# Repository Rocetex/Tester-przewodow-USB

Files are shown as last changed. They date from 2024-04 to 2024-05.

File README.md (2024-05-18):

# Tester przewodow USB
## Wstęp:
Jako projekt wstępnie wybrano tester przewodów USB. Wymagania przyjęte do tego projektu były następujące: stosunkowo niski koszt, prostota obsługi, kompaktowość i wszechstronność. Zdecydowano się, aby tester przeznaczony był dla przewodów USB type C - USB type C. Po podłączeniu przewodów do urządzenia  powinno ono podświetleniem poszczególnych diod ukazywać w jakim trybie może działać dany przewód, oraz możliwe uszkodzenia i cięcia budżetowe producenta w jego strukturze. 

## Założenia projektu:
* Możliwość testu 2 typów przewodów: USB A -> USB C oraz USB C -> USB C
* Dwa tryby częstotliwości pracy układu
* Kompaktowość urządzenia
* Niska cena
  
## Schemat i projekt układu
Wstępny zamysł projektu był następujący. Odpowiednio zaprojektowany system zegara CLK oparty o układ scalony NE555. Następnie sygnał ten przechodzi na 5 przerzutników typu JK działających w układzie licznika synchronicznego od 0 - 24, dzięki czemu możliwe było obsłużenie wszystkich 25 sygnałów pełnego złącza USB type C (a dokładniej 24 pinów sygnałowych oraz shielda). W ten sposób zaprojektowano układ licznika 5 bitowego. Sygnał z poszczególnych wyjść liczników trafia na dwa 4 bitowe dekodery połączone w odpowiedni sposób, zamiast na jeden dekoder 5 bitowy. Wynika to z faktu dostępności i ceny. Układ dwóch 4 bitowych dekoderów jest tańszy i łatwiej dostępny. Sygnał z poszczególnych wyjść dekoderów trafiał na odpowiednie mosfety typu P, a one po otrzymaniu sygnału załączeniowego (logiczne “0”) zaczynały przewodzić do odpowiedniego pinu złącza USB C. Następnie przez przewód sygnał trafiał na odpowiednie szeregowo połączone rezystory i diody, które zaczynały świecić, sygnalizująć działanie danego pinu.



## Instrukcja obsługi:
Płytkę należy zasilić napięciem 5V. 
Switch S1 odowiada za resetowanie układu.
Przełącznik S3 odpowiada za wybranie częstotliwości pracy układu
Przełącznik S4 odpowiada za wybranie trybu pracy:
1) USB typu A
2) USB typu C
Aby przetestować przewód USB A -> USB C:
- Podłączyć zasilanie do płytki
- Ustawić oczelowamą częstotliwość pracy układu
- Ustawić tryb pracy na USB A
- Wpiąć przewód z złącze USB A (oznaczone na płytce jako J3) oraz w wyjściowe złącze USB typu C (J2)
Aby przetestować przewód USB C -> USB C:
- Podłączyć zasilanie do płytki
- Ustawić oczelowamą częstotliwość pracy układu
- Ustawić tryb pracy na USB C
- Wpiąć przewód z złącze USB C (oznaczone na płytce jako J1) oraz w wyjściowe złącze USB typu C (J2)

## Błędy w konstrukcji płytki:
- Kondensator C3 należy przylutować równolegle do masy oraz do zwartych padów miejsca kondensatora
- Pomimo wykonania symulacji zauważono problem z zamykaniem się mosfetów, z tego powodu zaleca się użycie tranzystorów PNP oraz rezystorów na bramce 1k Ohm

## Prezentacja układu:






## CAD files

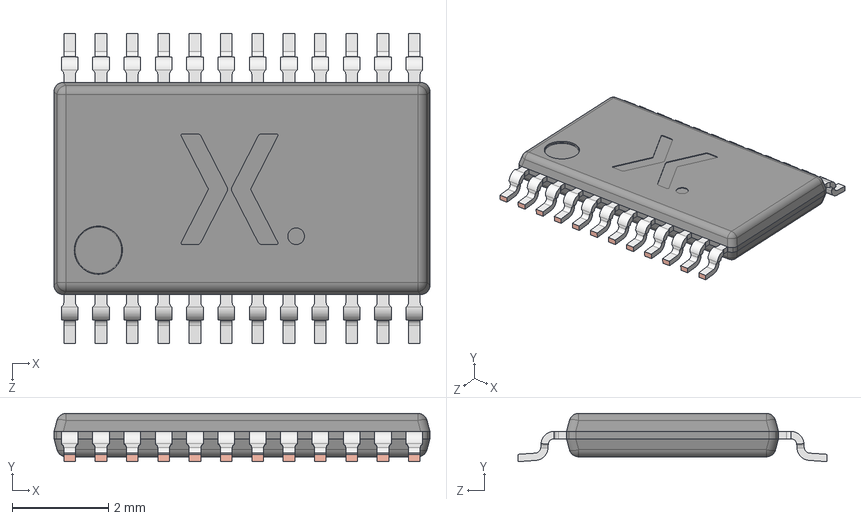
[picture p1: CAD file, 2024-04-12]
schematic/libadds/LIB_74HC154PW,118/74HC154PW,118/3D/74HC154PW,118.stp
7.80 x 1.00 x 6.42 mm
SOT355-1 Lower Mold body
SOT355-1 Lead
SOT355-1 Upper Mold body

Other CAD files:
schematic/libadds/LIB_74HC154PW,118/74HC154PW,118/Allegro/sop65p640x110-24n.psm
schematic/libadds/LIB_74HC154PW,118/74HC154PW,118/DEHDL/74hc154pw_118/chips/chips.prt

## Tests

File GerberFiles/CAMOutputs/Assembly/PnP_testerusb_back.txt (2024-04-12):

C10	57.68	83.24	180.00	100n	C0805
C15	40.66	85.68	180.00	100n	C0805
C6	36.33	72.73	90.00	100n	C0805
C7	45.77	59.92	270.00	100n	C0805
D1	55.88	27.15	270.00	5988170107F	LEDC2012X70N
D10	89.40	27.00	270.00	5988170107F	LEDC2012X70N
D11	93.20	26.94	270.00	5988170107F	LEDC2012X70N
D12	97.00	27.03	270.00	5988170107F	LEDC2012X70N
D13	97.00	33.48	90.00	5988170107F	LEDC2012X70N
D14	93.20	33.39	90.00	5988170107F	LEDC2012X70N
D15	89.40	33.50	90.00	5988170107F	LEDC2012X70N
D16	85.80	33.41	90.00	5988170107F	LEDC2012X70N
D17	81.80	33.32	90.00	5988170107F	LEDC2012X70N
D18	78.00	33.43	90.00	5988170107F	LEDC2012X70N
D19	74.20	33.34	90.00	5988170107F	LEDC2012X70N
D2	59.68	27.24	270.00	5988170107F	LEDC2012X70N
D20	70.60	33.45	90.00	5988170107F	LEDC2012X70N
D21	66.88	33.55	90.00	5988170107F	LEDC2012X70N
D22	63.28	33.46	90.00	5988170107F	LEDC2012X70N
D23	59.68	33.57	90.00	5988170107F	LEDC2012X70N
D24	55.88	33.48	90.00	5988170107F	LEDC2012X70N
D25	51.48	33.59	90.00	5988170107F	LEDC2012X70N
D3	63.28	27.13	270.00	5988170107F	LEDC2012X70N
D4	66.88	27.02	270.00	5988170107F	LEDC2012X70N
D5	70.48	27.11	270.00	5988170107F	LEDC2012X70N
D6	74.28	27.20	270.00	5988170107F	LEDC2012X70N
D7	77.88	27.09	270.00	5988170107F	LEDC2012X70N
D8	81.68	26.98	270.00	5988170107F	LEDC2012X70N
D9	85.68	27.07	270.00	5988170107F	LEDC2012X70N
IC2	31.12	66.54	90.00	74HC154PW,118	SOP65P640X110-24N
IC3	32.92	82.24	0.00	74HC107D	SO14
IC4	42.98	66.95	90.00	74HC107D	SO14
Q13	63.63	50.56	270.00	MMFTP84W	SUPER-SOT3
Q14	58.23	50.59	270.00	MMFTP84W	SUPER-SOT3
Q15	52.83	50.62	270.00	MMFTP84W	SUPER-SOT3
Q16	47.43	50.45	270.00	MMFTP84W	SUPER-SOT3
Q17	42.03	50.48	270.00	MMFTP84W	SUPER-SOT3
Q18	36.63	50.51	270.00	MMFTP84W	SUPER-SOT3
Q19	31.03	50.34	270.00	MMFTP84W	SUPER-SOT3
Q20	25.63	50.37	270.00	MMFTP84W	SUPER-SOT3
Q21	20.25	50.16	270.00	MMFTP84W	SUPER-SOT3
Q22	15.25	50.19	270.00	MMFTP84W	SUPER-SOT3
Q23	9.65	50.02	270.00	MMFTP84W	SUPER-SOT3
Q24	4.25	50.25	270.00	MMFTP84W	SUPER-SOT3
R16	64.72	54.76	270.00	100	R0805
R17	59.32	54.81	270.00	100	R0805
R18	53.97	54.71	270.00	100	R0805
R19	48.57	54.86	270.00	100	R0805
R20	43.23	54.79	270.00	100	R0805
R21	37.77	54.76	270.00	100	R0805
R22	32.17	54.71	270.00	100	R0805
R23	26.77	54.66	270.00	100	R0805
R24	21.37	54.61	270.00	100	R0805
R25	16.37	54.66	270.00	100	R0805
R26	10.67	54.61	270.00	100	R0805
R27	5.37	54.66	270.00	100	R0805
R29	55.93	21.76	270.00	100	R0805
R30	59.73	21.71	270.00	100	R0805
R31	63.33	21.66	270.00	100	R0805
R32	66.93	21.61	270.00	100	R0805
R33	70.58	21.51	270.00	100	R0805
R34	74.18	21.46	270.00	100	R0805
R35	77.98	21.41	270.00	100	R0805
R36	81.78	21.36	270.00	100	R0805
R37	85.58	21.31	270.00	100	R0805
R38	89.38	21.26	270.00	100	R0805
R39	93.18	21.21	270.00	100	R0805
R40	96.98	21.16	270.00	100	R0805
R41	97.02	38.89	90.00	100	R0805
R42	93.22	38.94	90.00	100	R0805
R43	89.42	38.99	90.00	100	R0805
R44	85.82	39.04	90.00	100	R0805
R45	81.82	39.09	90.00	100	R0805
R46	78.02	39.14	90.00	100	R0805
R47	74.22	39.19	90.00	100	R0805
R48	70.57	39.09	90.00	100	R0805
R49	66.77	39.14	90.00	100	R0805
R50	63.37	39.19	90.00	100	R0805
R51	59.77	39.24	90.00	100	R0805
R52	55.97	39.29	90.00	100	R0805
R53	51.37	39.14	90.00	100	R0805
U2	33.69	73.94	90.00	74LVC1G11DW-7	SOT65P210X110-6N
U3	47.71	79.47	90.00	74HC21D	SOIC127P600X175-14N

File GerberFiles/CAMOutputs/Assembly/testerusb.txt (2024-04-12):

Partlist exported from H:/kuelab/pcb/testerusb/testerusb.sch at 02.06.2023 18:42

Qty Value              Device                        Package                Parts                                                                                                                                                                                                                                              Description                                                                  ARROW_PART_NUMBER ARROW_PRICE-STOCK                                                  AVAILABILITY DESCRIPTION                                                                                                                           HEIGHT         MANUFACTURER_NAME MANUFACTURER_PART_NUMBER MF                MOUSER_PART_NUMBER          MOUSER_PRICE-STOCK                                                                               MP              MPN          OC_FARNELL OC_NEWARK PACKAGE                    POPULARITY PRICE PURCHASE-URL                                                     SPICEPREFIX
1                      10-XX                         B3F-10XX               S1                                                                                                                                                                                                                                                 OMRON SWITCH                                                                                                                                                                                                                                                                                                                                                                                                                                                                                                                                  B3F-1000     176432     36M3542                              72                                                                                           
2                      3,81/1,4                      3,81/1,4               GND, VCC                                                                                                                                                                                                                                           THROUGH-HOLE PAD                                                                                                                                                                                                                                                                                                                                                                                                                                                                                                                                                                                           14                                                                                           
1                      MUN2211T1-NPN_DRIVER-SC59-BEC SC59-BEC               T1                                                                                                                                                                                                                                                 NPN Bias Resistor Transistor                                                                                                                                                                                                                                                                                                                                                                                                                                                                                                                                                                               1                                                                                            
1                      R-EU_1812X7R                  1812X7R                F                                                                                                                                                                                                                                                  RESISTOR, European symbol                                                                                                                                                                                                                                                                                                                                                                                                                                                                                                                                                                                  0                                                                                 R          
1                      ZENER-DIODEP1-12              P1Z12                  D26                                                                                                                                                                                                                                                Z-Diode                                                                                                                                                                                                                                                                                                                                                                                                                                                                                                                                                                                                    0                                                                                            
1   0483930003         0483930003                    MOLEX_0483930003       J3                                                                                                                                                                                                                                                 Usb Rec 4p Ra Type a 15au Check availability                                                                                                                      In Stock      USB-A (USB TYPE-A) USB 3.2 Gen 1 (USB 3.1 Gen 1, Superspeed (USB 3.0)) Receptacle Connector 9 Position Through Hole, Right Angle                                                               Molex                                                                                                                                          0483930003                                        None                                  None  https://pricing.snapeda.com/search/part/0483930003/?ref=eda                 
50  100                R-EU_R0805                    R0805                  R4, R5, R6, R7, R8, R9, R10, R11, R12, R13, R14, R15, R16, R17, R18, R19, R20, R21, R22, R23, R24, R25, R26, R27, R28, R29, R30, R31, R32, R33, R34, R35, R36, R37, R38, R39, R40, R41, R42, R43, R44, R45, R46, R47, R48, R49, R50, R51, R52, R53 RESISTOR, European symbol                                                                                                                                                                                                                                                                                                                                                                                                                                                                                                                                                                                  86                                                                                R          
15  100n               C-EUC0805                     C0805                  C3, C5, C6, C7, C8, C9, C10, C11, C12, C13, C14, C15, C16, C17, C18                                                                                                                                                                                CAPACITOR, European symbol                                                                                                                                                                                                                                                                                                                                                                                                                                                                                                                                                                                 88                                                                                C          
1   1k                 R-EU_R0805                    R0805                  R3                                                                                                                                                                                                                                                 RESISTOR, European symbol                                                                                                                                                                                                                                                                                                                                                                                                                                                                                                                                                                                  86                                                                                R          
1   33                 R-EU_0207/10                  0207/10                R1                                                                                                                                                                                                                                                 RESISTOR, European symbol                                                                                                                                                                                                                                                                                                                                                                                                                                                                                                                                                                                  81                                                                                R          
2   47n                C-EU025_050-035X075           C025_050-035X075       C2, C4                                                                                                                                                                                                                                             CAPACITOR, European symbol                                                                                                                                                                                                                                                                                                                                                                                                                                                                                                                                                                                 0                                                                                 C          
1   47u                C-EU025_050-035X075           C025_050-035X075       C1                                                                                                                                                                                                                                                 CAPACITOR, European symbol                                                                                                                                                                                                                                                                                                                                                                                                                                                                                                                                                                                 0                                                                                 C          
25  5988170107F        5988170107F                   LEDC2012X70N           D1, D2, D3, D4, D5, D6, D7, D8, D9, D10, D11, D12, D13, D14, D15, D16, D17, D18, D19, D20, D21, D22, D23, D24, D25                                                                                                                                 Standard LEDs - SMD Green Water Clr 40mcd 570nm Check availability                                                                                                In Stock      Green 566nm LED Indication - Discrete 2V 0805 (2012 Metric)                                                                                                                                    Dialight                                                                                                                                       5988170107F                                       0805 Dialight                         None  https://pricing.snapeda.com/search/part/5988170107F/?ref=eda                
1   7.5k               R-EU_0207/10                  0207/10                R2                                                                                                                                                                                                                                                 RESISTOR, European symbol                                                                                                                                                                                                                                                                                                                                                                                                                                                                                                                                                                                  81                                                                                R          
2   74AHC1G08DCK       74AHC1G08DCK                  SC70-5                 IC6, IC7                                                                                                                                                                                                                                           2-input AND gate                                                                                                                                                                                                                                                                                                                                                                                                                                                                                                                                                                                           0                                                                                            
3   74AHC1G32DCK       74AHC1G32DCK                  SC70-5                 IC8, IC9, IC10                                                                                                                                                                                                                                     2-input OR gate                                                                                                                                                                                                                                                                                                                                                                                                                                                                                                                                                                                            0                                                                                            
3   74HC107D           74HC107D                      SO14                   IC3, IC4, IC5                                                                                                                                                                                                                                      Dual J-K FLIP FLOP, clear                                                                                                                                                                                                                                                                                                                                                                                                                                                                                                                                                                                  0                                                                                            
2   74HC154PW,118      74HC154PW,118                 SOP65P640X110-24N      IC1, IC2                                                                                                                                                                                                                                           Encoders, Decoders, Multiplexers & Demultiplexers 4-16 DECODER/DEMUX         74HC154PW,118     https://www.arrow.com/en/products/74hc154pw118/nexperia?region=nac              Encoders, Decoders, Multiplexers & Demultiplexers 4-16 DECODER/DEMUX                                                                  1.1mm          Nexperia          74HC154PW,118                              771-HC154PW118              https://www.mouser.co.uk/ProductDetail/Nexperia/74HC154PW118?qs=P62ublwmbi9%252BzQcGRVZVsg%3D%3D                                                                                                                                                                           
1   74HC21D            74HC21D                       SOIC127P600X175-14N    U3                                                                                                                                                                                                                                                 Dual 4-input AND gate Check availability                                                                                                                          In Stock      AND Gate IC 2 Channel - 14-SOIC                                                                                                                                                                Toshiba                                                                                                                                        74HC21D                                           SOIC-14 NXP Semiconductors            None  https://pricing.snapeda.com/search/part/74HC21D/?ref=eda                    
1   74LVC1G11DW-7      74LVC1G11DW-7                 SOT65P210X110-6N       U2                                                                                                                                                                                                                                                 SINGLE 3 INPUT POSITIVE AND GATE Check availability                                                                                                               In Stock      AND Gate IC 1 Channel - SOT-363                                                                                                                                                                Diodes Inc.                                                                                                                                    74LVC1G11DW-7                                     SOT-363 Diodes Inc.                   None  https://pricing.snapeda.com/search/part/74LVC1G11DW-7/?ref=eda              
25  MMFTP84W           FDN360P                       SUPER-SOT3             Q1, Q2, Q3, Q4, Q5, Q6, Q7, Q8, Q9, Q10, Q11, Q12, Q13, Q14, Q15, Q16, Q17, Q18, Q19, Q20, Q21, Q22, Q23, Q24, Q25                                                                                                                                 Single P-Channel, PowerTrench (R) MOSFET                                                                                                                                                                                                                                                                                                                                                                                                                                                                                                                                                                   2                                                                                            
1   NE555DR            NE555DR                       SOIC127P599X175-8N     U1                                                                                                                                                                                                                                                 None Check availability                                                                                                                                           In Stock      Single Precision Timer                                                                                                                                                                         Texas Instruments                                                                                                                              NE555DR                                           SOIC-8 Texas Instruments              None  https://pricing.snapeda.com/search/part/NE555DR/?ref=eda
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

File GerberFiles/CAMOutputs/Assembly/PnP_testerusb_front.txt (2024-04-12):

C11	93.28	71.91	270.00	100n	C0805
C12	20.08	79.59	90.00	100n	C0805
C13	17.16	69.28	180.00	100n	C0805
C14	42.29	90.72	0.00	100n	C0805
C16	36.91	76.58	180.00	100n	C0805
C17	10.96	62.48	180.00	100n	C0805
C18	24.00	66.80	0.00	100n	C0805
C3	60.43	90.93	90.00	100n	C0805
C5	9.17	79.22	270.00	100n	C0805
C8	15.03	77.33	90.00	100n	C0805
C9	96.11	65.87	180.00	100n	C0805
F	92.36	79.92	180.00		1812X7R
IC1	92.48	58.28	0.00	74HC154PW,118	SOP65P640X110-24N
IC10	9.63	66.08	90.00	74AHC1G32DCK	SC70-5
IC5	32.82	92.88	180.00	74HC107D	SO14
IC6	19.55	65.26	270.00	74AHC1G08DCK	SC70-5
IC7	13.37	72.20	270.00	74AHC1G08DCK	SC70-5
IC8	20.76	74.97	0.00	74AHC1G32DCK	SC70-5
IC9	20.83	70.92	90.00	74AHC1G32DCK	SC70-5
J1	14.02	8.61	0.00	USB4056-03-A_REVA2	GCT_USB4056-03-A_REVA2
J2	84.23	9.01	0.00	USB4056-03-A_REVA2	GCT_USB4056-03-A_REVA2
Q1	4.45	26.30	270.00	MMFTP84W	SUPER-SOT3
Q10	53.41	26.71	270.00	MMFTP84W	SUPER-SOT3
Q11	59.01	26.74	270.00	MMFTP84W	SUPER-SOT3
Q12	65.01	26.77	270.00	MMFTP84W	SUPER-SOT3
Q2	9.85	26.27	270.00	MMFTP84W	SUPER-SOT3
Q25	70.65	26.68	270.00	MMFTP84W	SUPER-SOT3
Q3	15.65	26.36	270.00	MMFTP84W	SUPER-SOT3
Q4	21.05	26.39	270.00	MMFTP84W	SUPER-SOT3
Q5	26.41	26.44	270.00	MMFTP84W	SUPER-SOT3
Q6	31.81	26.61	270.00	MMFTP84W	SUPER-SOT3
Q7	37.21	26.62	270.00	MMFTP84W	SUPER-SOT3
Q8	42.61	26.85	270.00	MMFTP84W	SUPER-SOT3
Q9	48.01	26.68	270.00	MMFTP84W	SUPER-SOT3
R10	75.02	41.03	270.00	100	R0805
R11	78.67	40.93	270.00	100	R0805
R12	82.14	41.10	270.00	100	R0805
R13	85.79	41.05	270.00	100	R0805
R14	89.31	41.05	270.00	100	R0805
R15	92.90	41.02	270.00	100	R0805
R28	96.47	41.01	270.00	100	R0805
R3	12.40	96.57	180.00	1k	R0805
R4	53.53	40.97	270.00	100	R0805
R5	57.09	40.97	270.00	100	R0805
R6	60.65	41.00	270.00	100	R0805
R7	64.22	40.99	270.00	100	R0805
R8	67.82	41.03	270.00	100	R0805
R9	71.41	41.01	270.00	100	R0805
T1	9.19	93.77	270.00		SC59-BEC
U1	52.54	91.95	90.00	NE555DR	SOIC127P599X175-8N
U4	88.07	71.97	0.00	SN74AHC1G14DBVR	SOT95P280X145-5N

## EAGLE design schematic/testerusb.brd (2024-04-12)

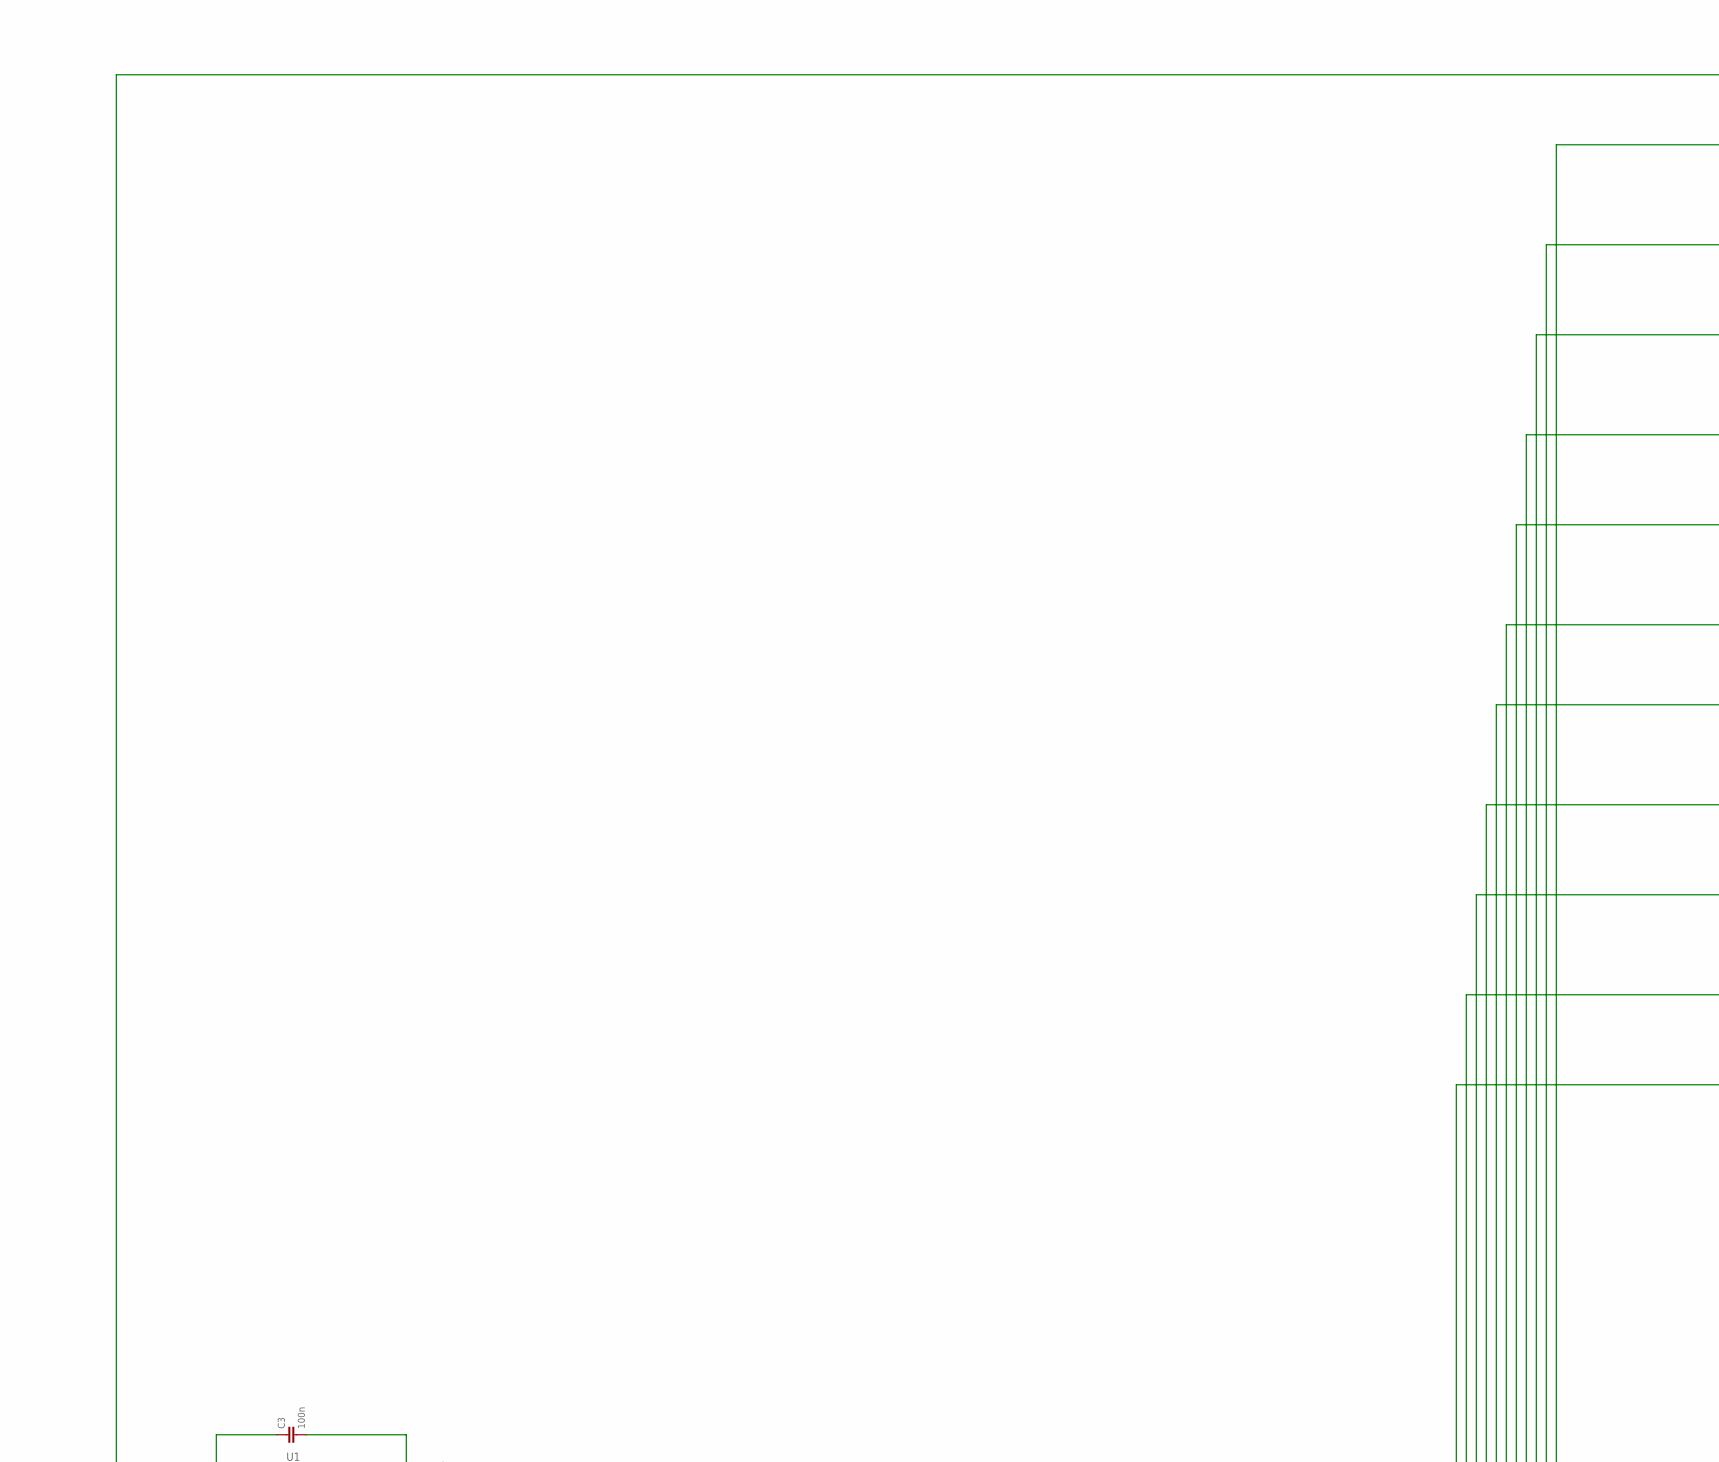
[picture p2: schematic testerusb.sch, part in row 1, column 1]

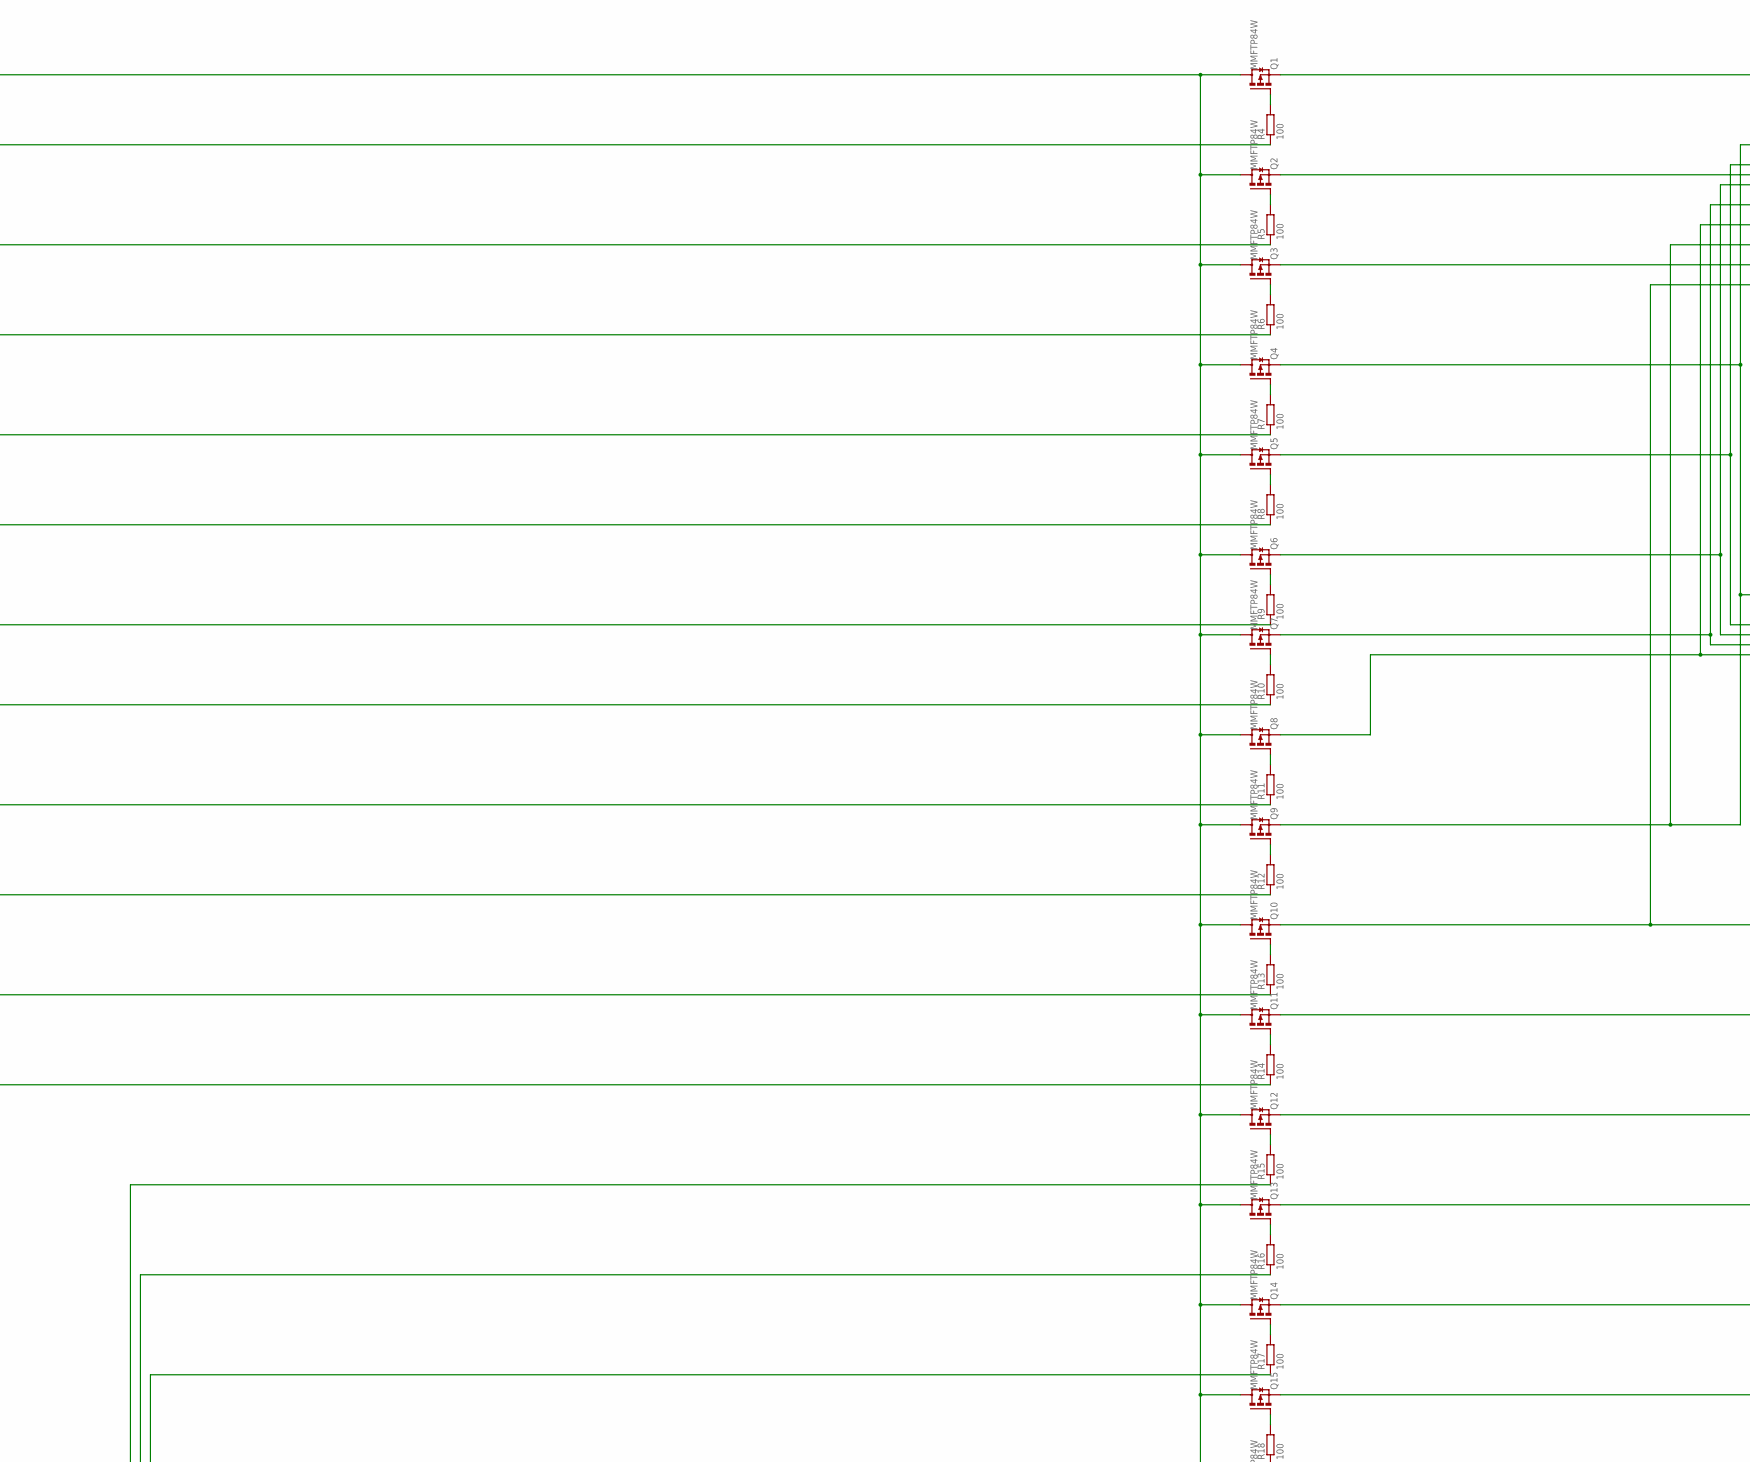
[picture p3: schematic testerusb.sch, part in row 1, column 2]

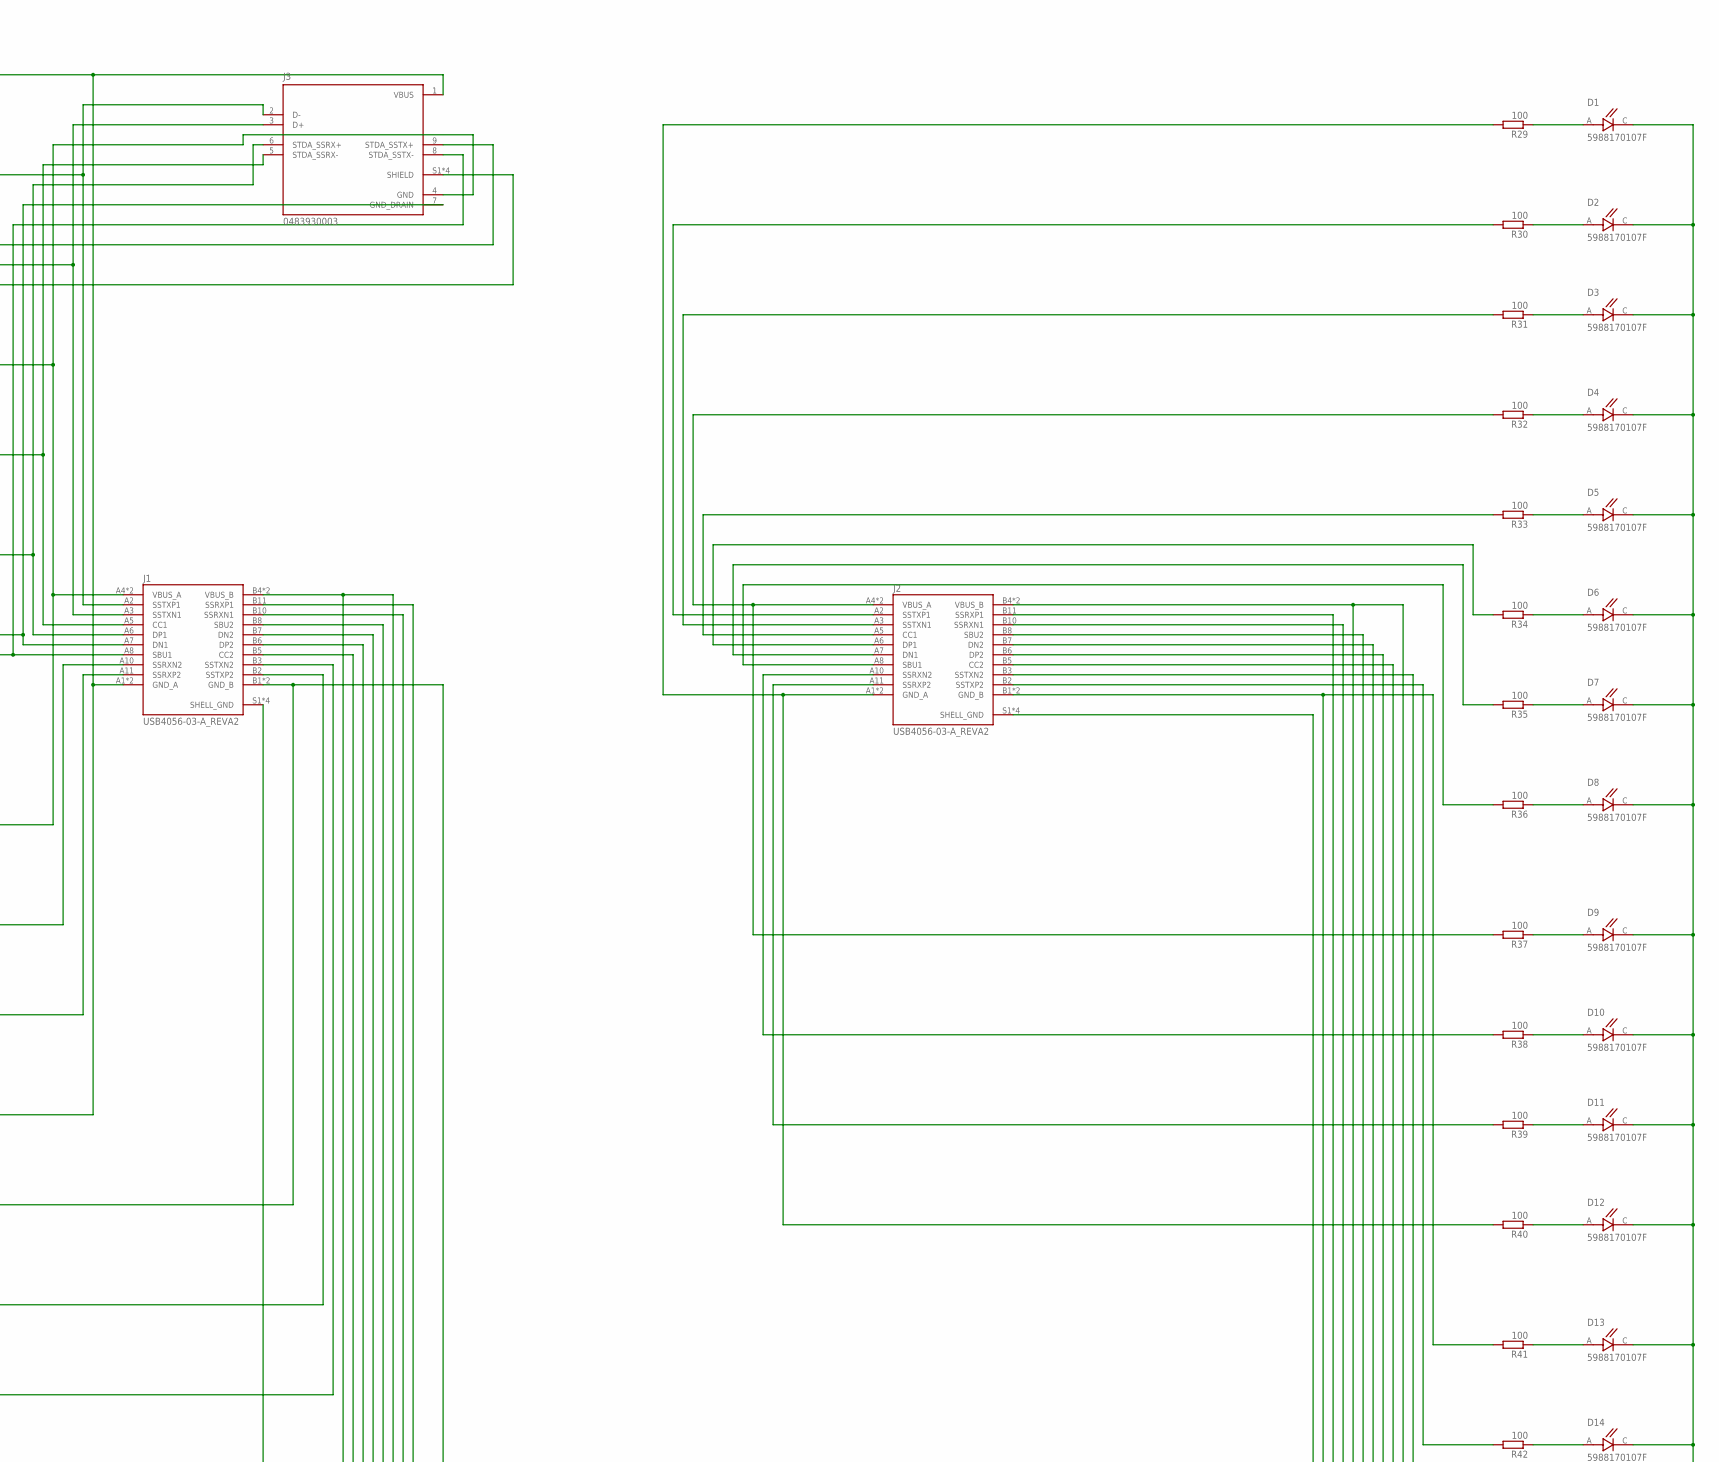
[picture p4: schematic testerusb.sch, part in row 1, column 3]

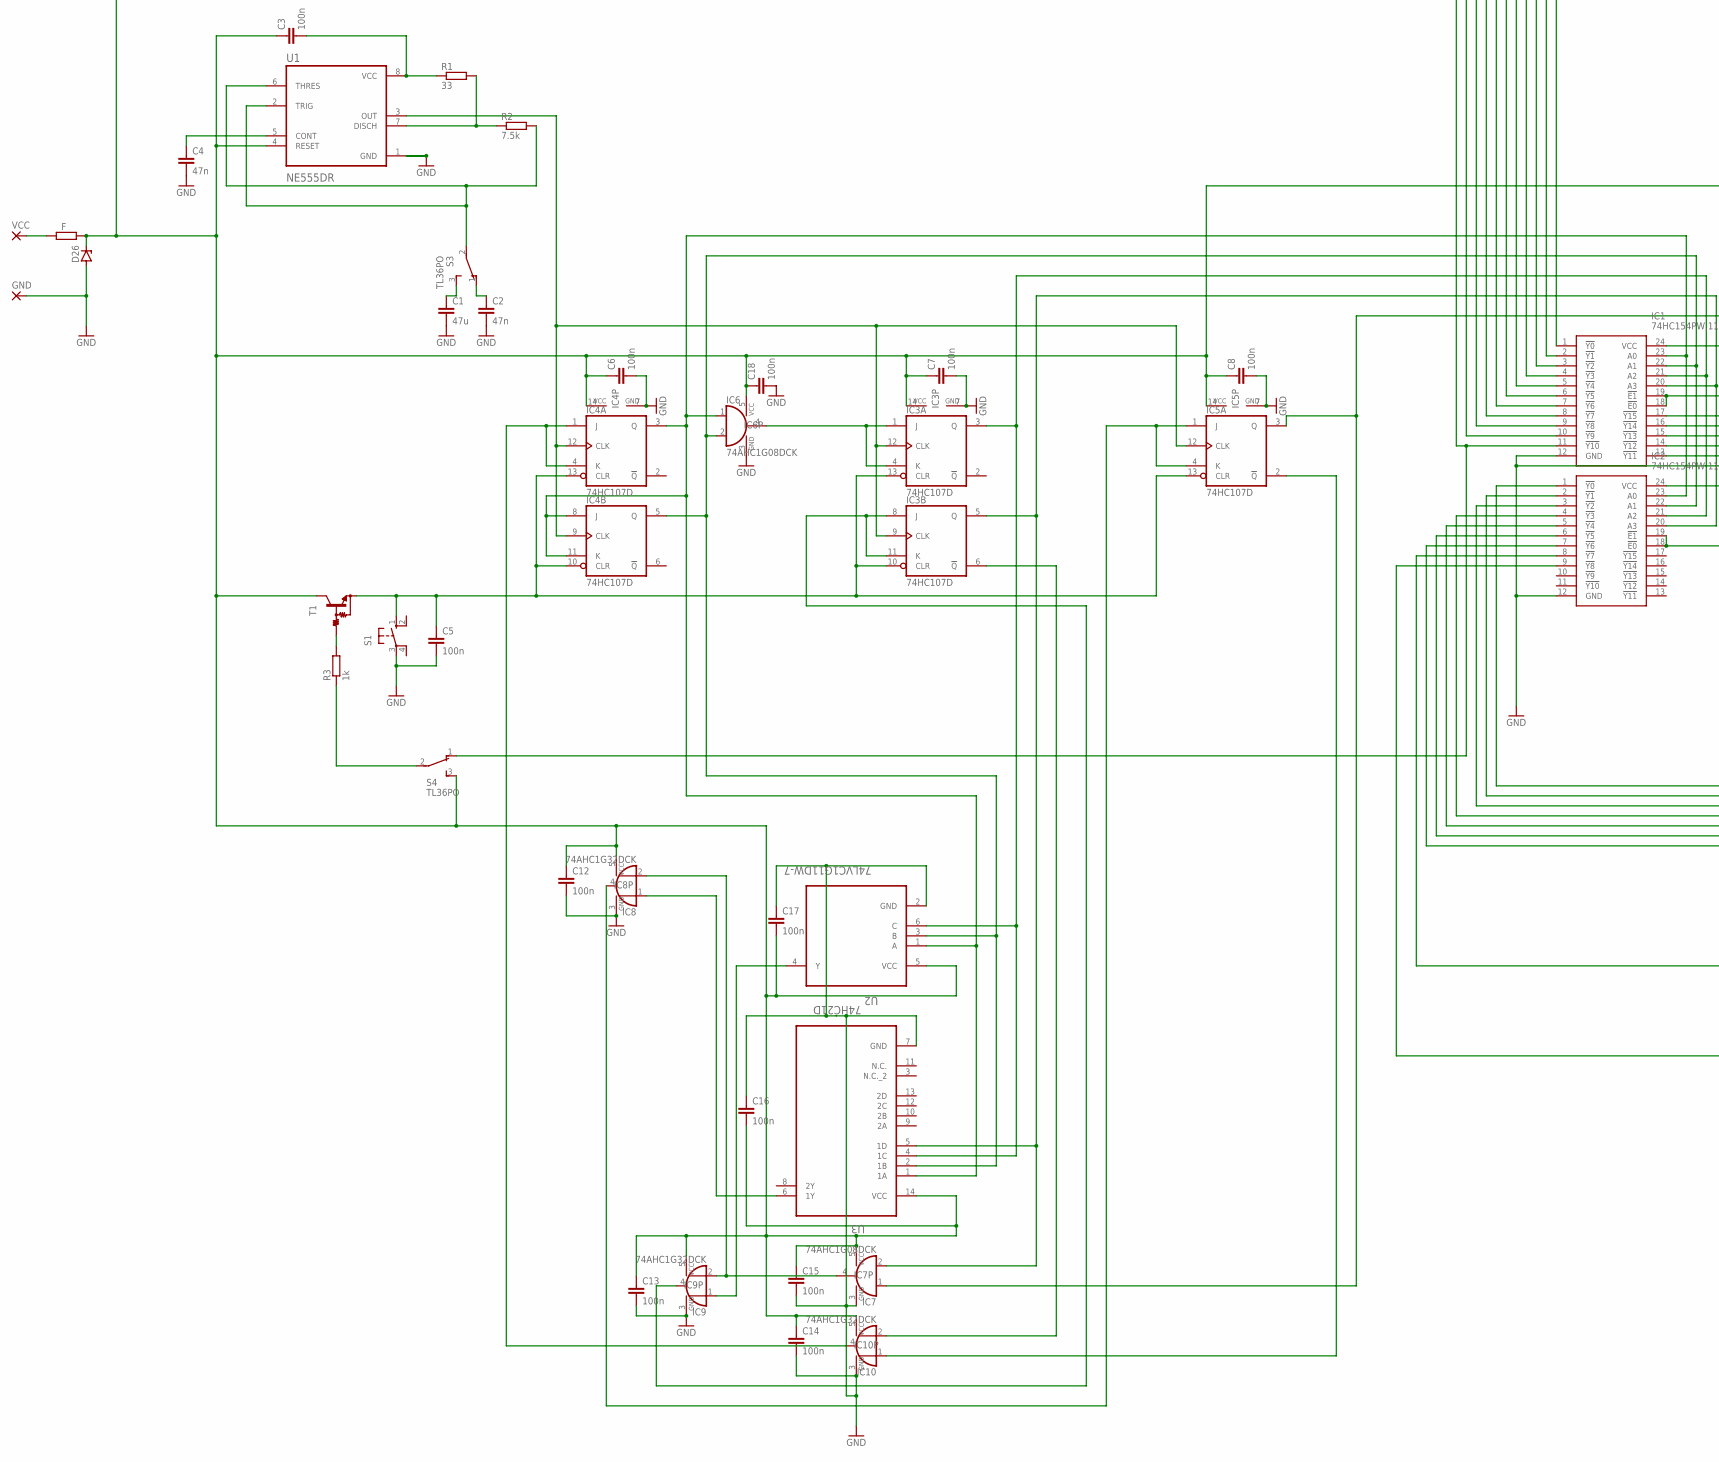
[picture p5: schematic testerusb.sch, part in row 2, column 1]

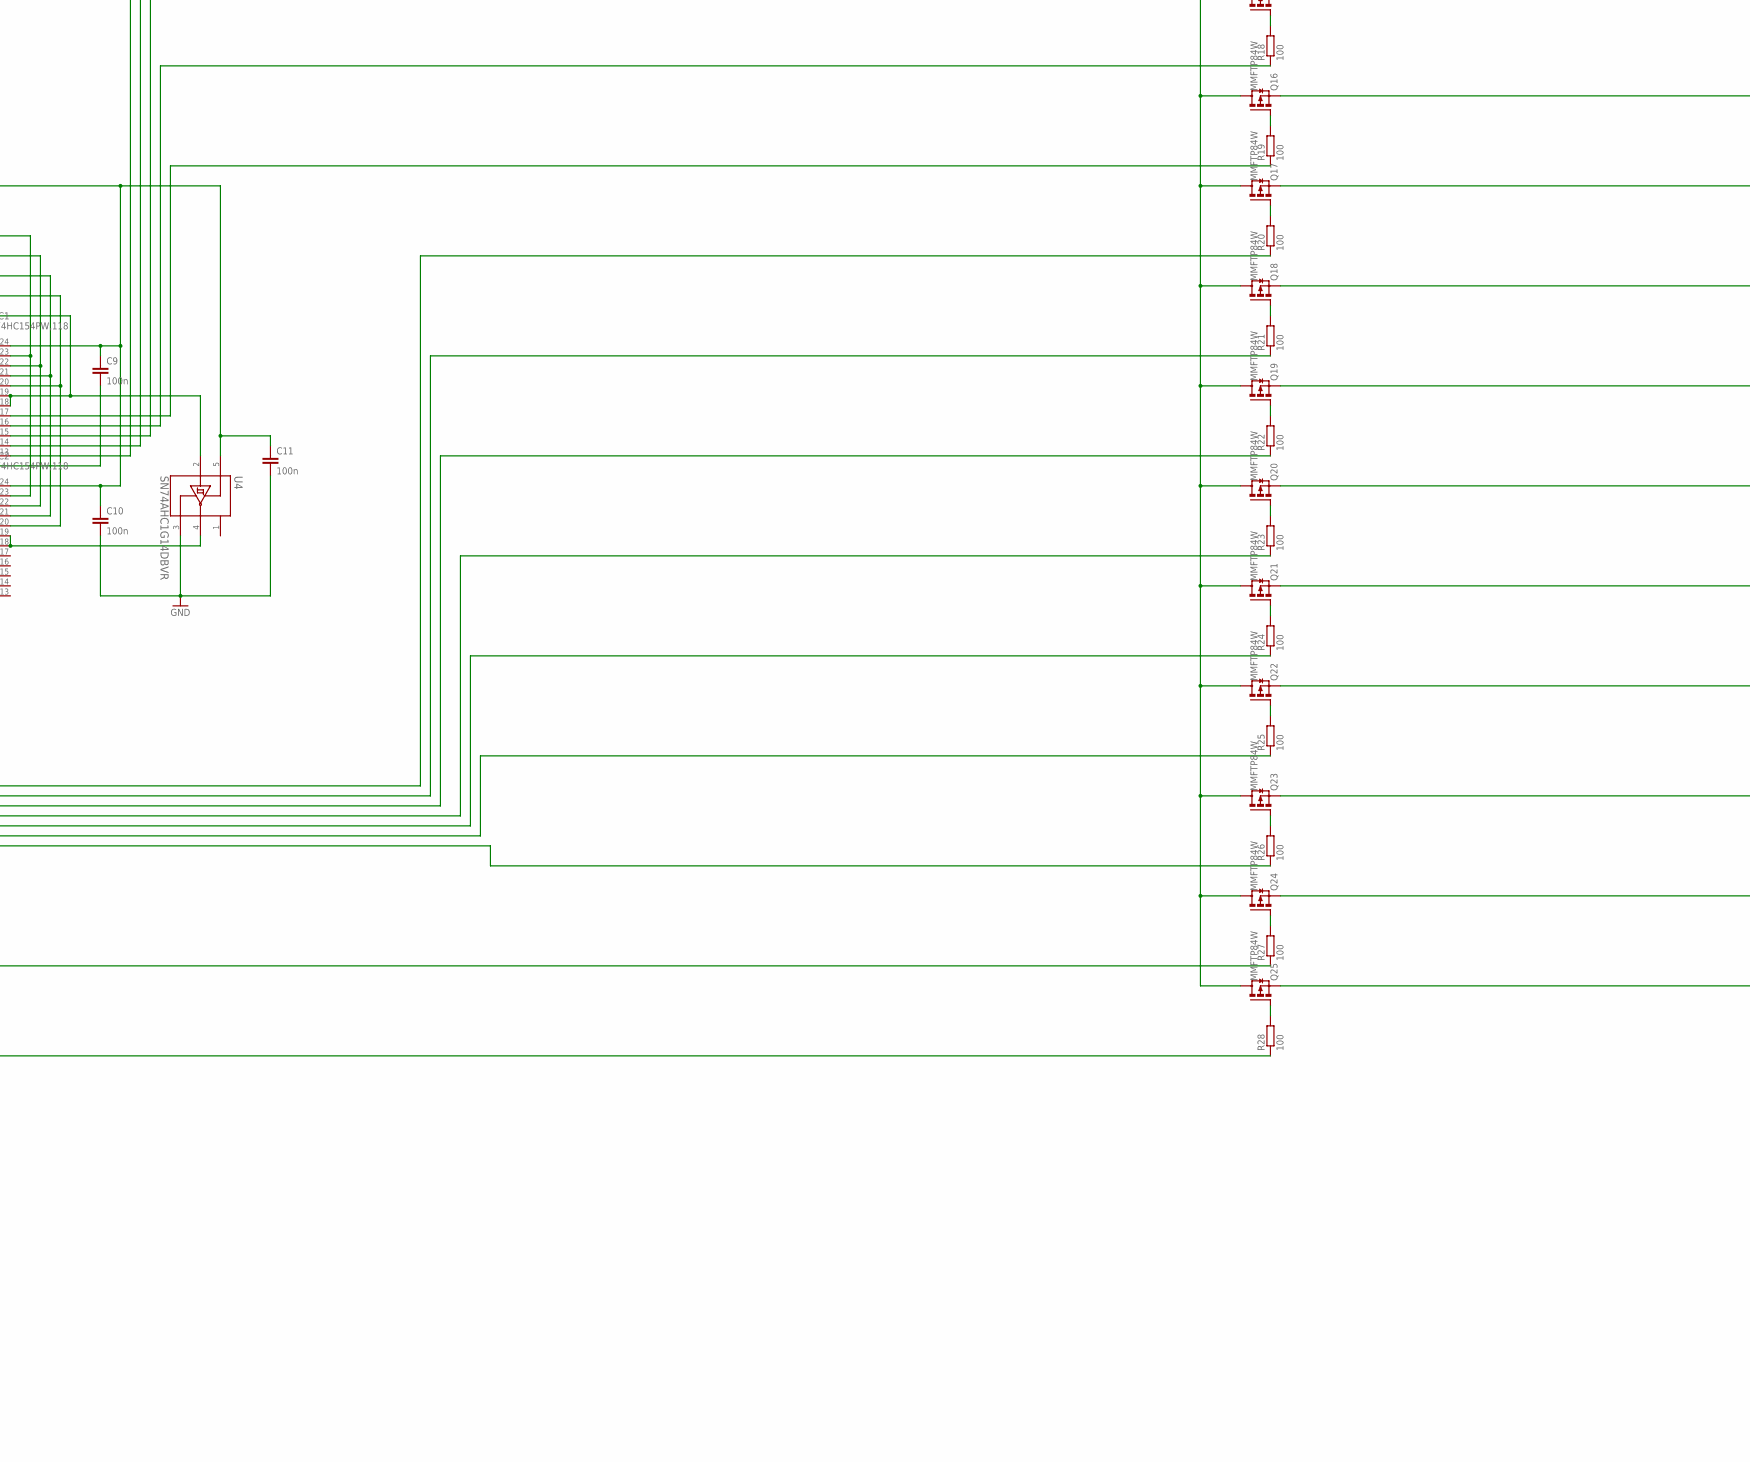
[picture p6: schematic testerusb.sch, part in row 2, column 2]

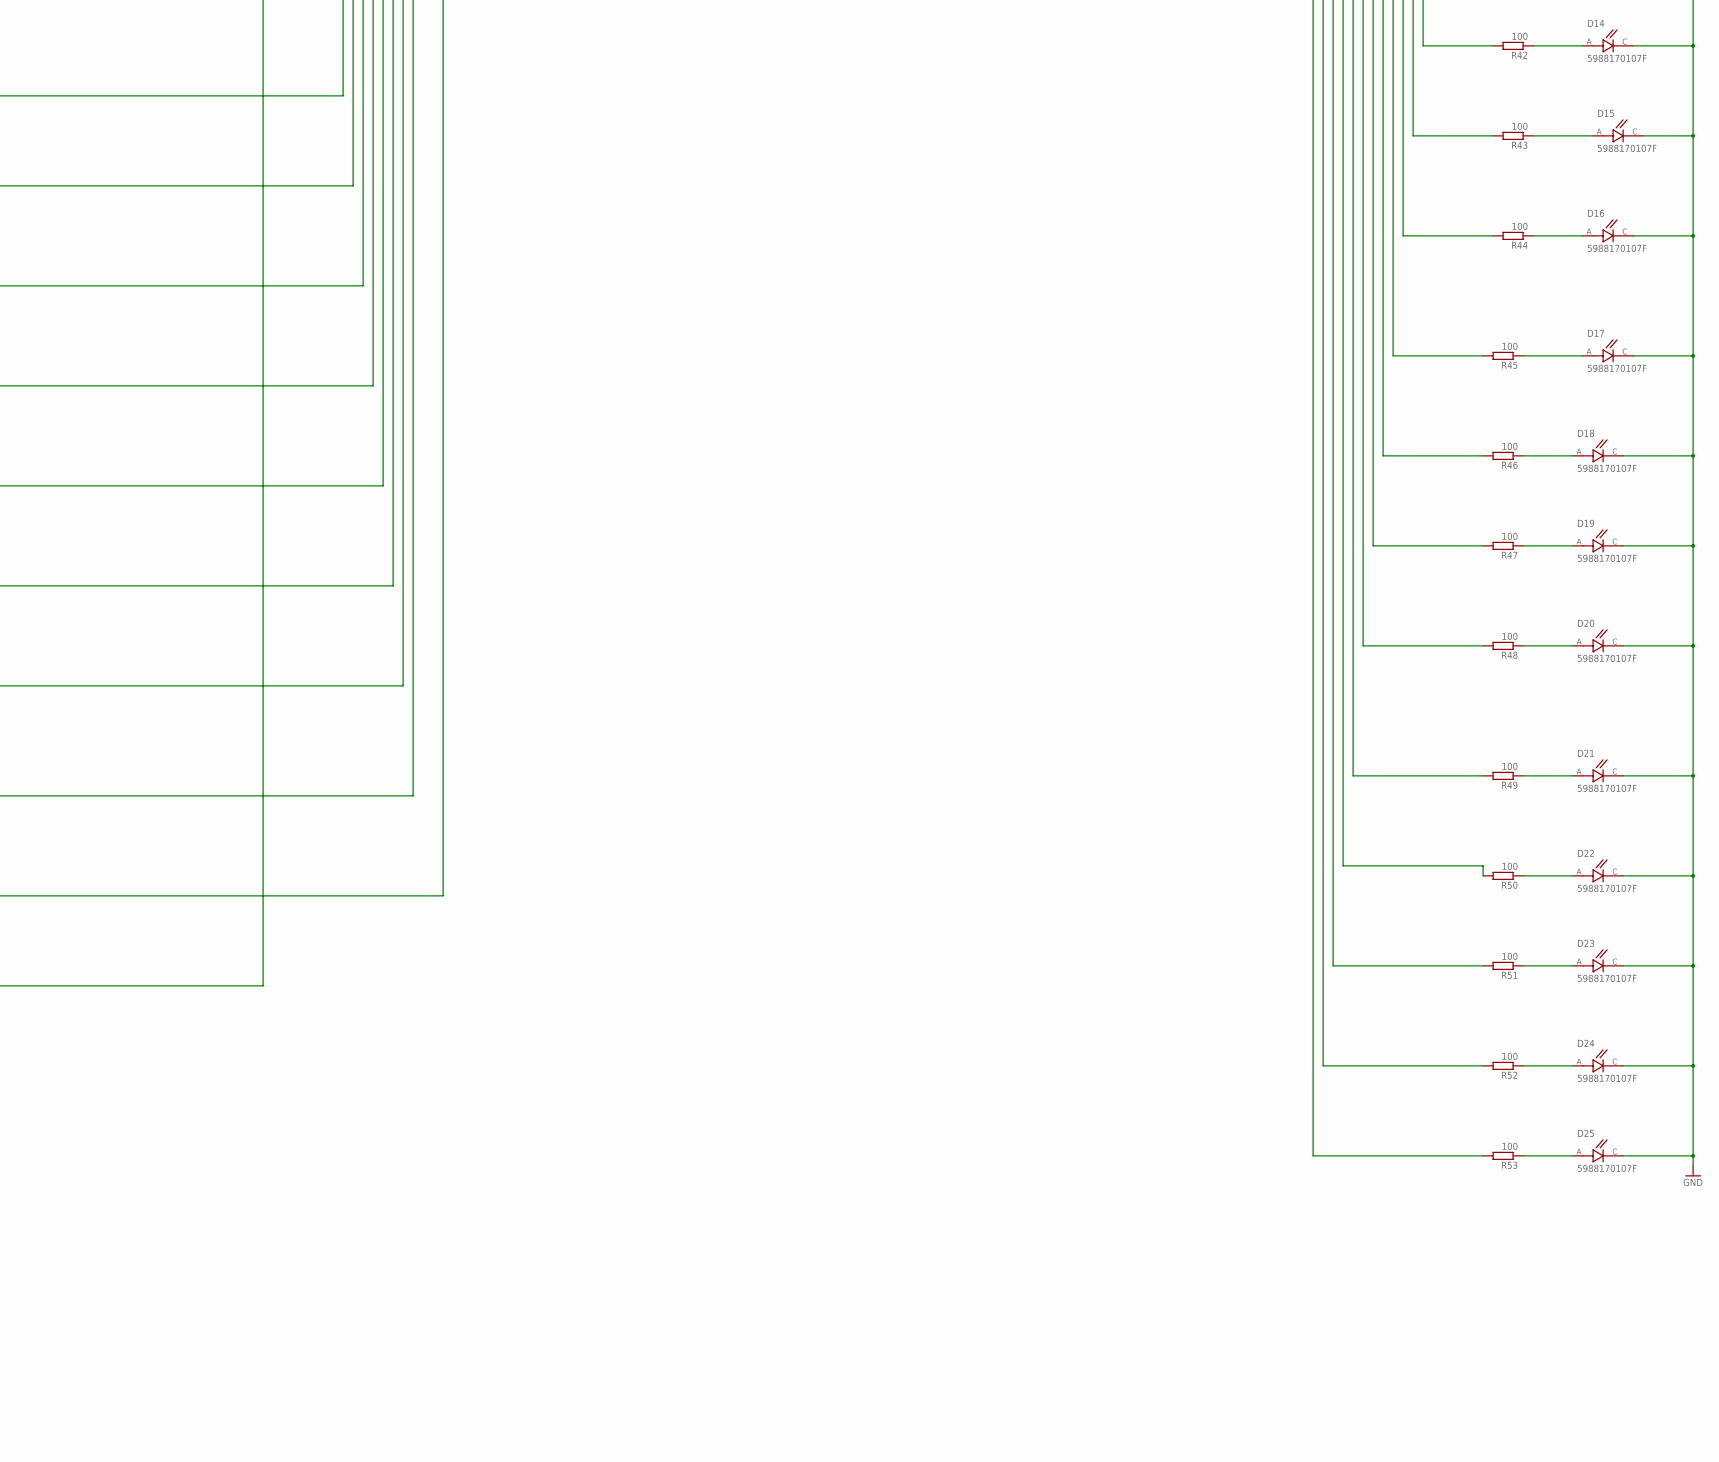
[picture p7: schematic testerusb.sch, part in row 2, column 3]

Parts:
C1: 47u; C025_050-035X075
C2, C4: 47n; C025_050-035X075
C3, C5, C6, C7, C8, C9, C10, C11, C12, C13, C14, C15, C16, C17, C18: 100n; C0805
D1, D2, D3, D4, D5, D6, D7, D8, D9, D10, D11, D12, D13, D14, D15, D16, D17, D18, D19, D20, D21, D22, D23, D24, D25: 5988170107F; LEDC2012X70N
D26: ZENER-DIODEP1-12; P1Z12
F: R-EU_1812X7R; 1812X7R
GND: 3,81/1,4
IC1, IC2: 74HC154PW,118; SOP65P640X110-24N
IC3, IC4, IC5: 74HC107D; SO14
IC6, IC7: 74AHC1G08DCK; SC70-5
IC8, IC9, IC10: 74AHC1G32DCK; SC70-5
J1, J2: USB4056-03-A_REVA2; GCT_USB4056-03-A_REVA2
J3: 0483930003; MOLEX_0483930003
Q1, Q2, Q3, Q4, Q5, Q6, Q7, Q8, Q9, Q10, Q11, Q12, Q13, Q14, Q15, Q16, Q17, Q18, Q19, Q20, Q21, Q22, Q23, Q24, Q25: MMFTP84W; SUPER-SOT3
R1: 33; 0207/10
R2: 7.5k; 0207/10
R3: 1k; R0805
R4, R5, R6, R7, R8, R9, R10, R11, R12, R13, R14, R15, R16, R17, R18, R19, R20, R21, R22, R23, R24, R25, R26, R27, R28, R29, R30, R31, R32, R33, R34, R35, R36, R37, R38, R39, R40, R41, R42, R43, R44, R45, R46, R47, R48, R49, R50, R51, R52, R53: 100; R0805
S1: 10-XX; B3F-10XX
S3, S4: TL36PO; TL3XPO
T1: MUN2211T1-NPN_DRIVER-SC59-BEC; SC59-BEC
U1: NE555DR; SOIC127P599X175-8N
U2: 74LVC1G11DW-7; SOT65P210X110-6N
U3: 74HC21D; SOIC127P600X175-14N
U4: SN74AHC1G14DBVR; SOT95P280X145-5N
VCC: 3,81/1,4

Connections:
GND: C1.2, C2.2, C4.2, C5.2, C6.2, C7.2, C8.2, C9.2, C10.2, C11.2, C12.2, C13.2, C14.2, C15.2, C16.1, C17.1, C18.2, D1.C, D2.C, D3.C, D4.C, D5.C, D6.C, D7.C, D8.C, D9.C, D10.C, D11.C, D12.C, D13.C, D14.C, D15.C, D16.C, D17.C, D18.C, D19.C, D20.C, D21.C, D22.C, D23.C, D24.C, D25.C, D26.A, GND.1, IC1.12 (GND), IC2.12 (GND), IC3.7 (GND), IC4.7 (GND), IC5.7 (GND), IC6.3 (GND), IC7.3 (GND), IC8.3 (GND), IC9.3 (GND), IC10.3 (GND), S1.3, U1.1 (GND), U2.2 (GND), U3.7 (GND), U4.3 (GND)
unnamed: Q1.1 (G), R4.2
unnamed: Q2.1 (G), R5.2
unnamed: IC4.1 (J), IC4.4 (K), IC10.4 (O)
unnamed: IC1.18 (!E0), IC1.19 (!E1), IC5.3 (Q), IC7.1 (I0), U4.2 (A)
unnamed: IC3.1 (J), IC3.4 (K), IC6.4 (O)
unnamed: IC3.8 (J), IC3.11 (K), IC9.4 (O)
unnamed: IC5.1 (J), IC5.4 (K), IC8.4 (O)
unnamed: F.1, VCC.1
unnamed: C1.1, S3.3 (S)
unnamed: C3.2, R1.1, U1.8 (VCC)
unnamed: C3.1, C6.1, C7.1, C8.1, C9.1, C10.1, C11.1, C12.1, C13.1, C14.1, C15.1, C16.2, C17.2, C18.1, D26.C, F.2, IC1.24 (VCC), IC2.24 (VCC), IC3.14 (VCC), IC4.14 (VCC), IC5.14 (VCC), IC6.5 (VCC), IC7.5 (VCC), IC8.5 (VCC), IC9.5 (VCC), IC10.5 (VCC), Q1.3 (D), Q2.3 (D), Q3.3 (D), Q4.3 (D), Q5.3 (D), Q6.3 (D), Q7.3 (D), Q8.3 (D), Q9.3 (D), Q10.3 (D), Q11.3 (D), Q12.3 (D), Q13.3 (D), Q14.3 (D), Q15.3 (D), Q16.3 (D), Q17.3 (D), Q18.3 (D), Q19.3 (D), Q20.3 (D), Q21.3 (D), Q22.3 (D), Q23.3 (D), Q24.3 (D), Q25.3 (D), S4.3 (S), T1.C, U1.4 (RESET), U2.5 (VCC), U3.14 (VCC), U4.5 (VCC)
unnamed: R1.2, R2.1, U1.7 (DISCH)
unnamed: C4.1, U1.5 (CONT)
unnamed: C2.1, S3.1 (O)
unnamed: R2.2, S3.2, U1.2 (TRIG), U1.6 (THRES)
unnamed: IC3.9 (CLK), IC3.12 (CLK), IC4.9 (CLK), IC4.12 (CLK), IC5.12 (CLK), U1.3 (OUT)
unnamed: R3.2, T1.B
unnamed: C5.1, IC3.10 (CLR), IC3.13 (CLR), IC4.10 (CLR), IC4.13 (CLR), IC5.13 (CLR), S1.1 (S), T1.E
unnamed: IC1.2 (!Y1), R5.1
unnamed: R3.1, S4.2
unnamed: IC1.11 (!Y10), R14.1, S4.1 (O)
unnamed: IC3.6 (!Q), IC10.2 (I1)
unnamed: IC1.22 (A1), IC2.22 (A1), IC4.5 (Q), IC6.2 (I1), U2.3 (B), U3.2 (1B)
unnamed: IC1.23 (A0), IC2.23 (A0), IC4.3 (Q), IC4.8 (J), IC4.11 (K), IC6.1 (I0), U2.1 (A), U3.1 (1A)
unnamed: IC2.18 (!E0), IC2.19 (!E1), U4.4 (Y)
unnamed: IC5.2 (!Q), IC10.1 (I0)
unnamed: IC7.4 (O), IC8.2 (I1), IC9.2 (I1)
unnamed: IC9.1 (I0), U2.4 (Y)
unnamed: IC1.21 (A2), IC2.21 (A2), IC3.3 (Q), U2.6 (C), U3.4 (1C)
unnamed: IC1.20 (A3), IC2.20 (A3), IC3.5 (Q), IC7.2 (I1), U3.5 (1D)
unnamed: IC8.1 (I0), U3.6 (1Y)
unnamed: IC1.1 (!Y0), R4.1
unnamed: IC1.3 (!Y2), R6.1
unnamed: IC1.4 (!Y3), R7.1
unnamed: IC1.5 (!Y4), R8.1
unnamed: IC1.6 (!Y5), R9.1
unnamed: IC1.7 (!Y6), R10.1
unnamed: IC1.8 (!Y7), R11.1
unnamed: IC1.9 (!Y8), R12.1
unnamed: IC1.10 (!Y9), R13.1
unnamed: IC1.13 (!Y11), R15.1
unnamed: IC1.14 (!Y12), R16.1
unnamed: IC1.15 (!Y13), R17.1
unnamed: IC1.16 (!Y14), R18.1
unnamed: IC1.17 (!Y15), R19.1
unnamed: IC2.1 (!Y0), R20.1
unnamed: IC2.9 (!Y8), R28.1
unnamed: IC2.2 (!Y1), R21.1
unnamed: IC2.3 (!Y2), R22.1
unnamed: IC2.4 (!Y3), R23.1
unnamed: IC2.5 (!Y4), R24.1
unnamed: IC2.6 (!Y5), R25.1
unnamed: IC2.7 (!Y6), R26.1
unnamed: IC2.8 (!Y7), R27.1
unnamed: Q3.1 (G), R6.2
unnamed: Q4.1 (G), R7.2
unnamed: Q5.1 (G), R8.2
unnamed: Q6.1 (G), R9.2
unnamed: Q7.1 (G), R10.2
unnamed: Q8.1 (G), R11.2
unnamed: Q9.1 (G), R12.2
unnamed: Q10.1 (G), R13.2
unnamed: Q11.1 (G), R14.2
unnamed: Q12.1 (G), R15.2
unnamed: Q13.1 (G), R16.2
unnamed: Q14.1 (G), R17.2
unnamed: Q15.1 (G), R18.2
unnamed: Q16.1 (G), R19.2
unnamed: Q17.1 (G), R20.2
unnamed: Q18.1 (G), R21.2
unnamed: Q19.1 (G), R22.2
unnamed: Q20.1 (G), R23.2
unnamed: Q21.1 (G), R24.2
unnamed: Q22.1 (G), R25.2
unnamed: Q23.1 (G), R26.2
unnamed: Q24.1 (G), R27.2
unnamed: Q25.1 (G), R28.2
unnamed: D1.A, R29.1
unnamed: J1.A1 (GND_A), J1.A12 (GND_A), J3.1 (VBUS), Q1.2 (S), Q12.2 (S)
unnamed: J1.B1 (GND_B), J1.B12 (GND_B), Q13.2 (S), Q24.2 (S)
unnamed: J1.A2 (SSTXP1), J3.2 (D-), Q2.2 (S)
unnamed: J1.A3 (SSTXN1), J3.3 (D+), Q3.2 (S)
unnamed: J1.A4 (VBUS_A), J1.A9 (VBUS_A), J3.4 (GND), J3.9 (STDA_SSTX+), Q4.2 (S), Q9.2 (S)
unnamed: J1.A5 (CC1), J3.5 (STDA_SSRX-), Q5.2 (S)
unnamed: J1.A6 (DP1), J3.6 (STDA_SSRX+), Q6.2 (S)
unnamed: J1.A7 (DN1), J3.7 (GND_DRAIN), Q7.2 (S)
unnamed: J1.A8 (SBU1), J3.8 (STDA_SSTX-), Q8.2 (S)
unnamed: J1.A10 (SSRXN2), J3.S1 (SHIELD), J3.S2 (SHIELD), J3.S3 (SHIELD), J3.S4 (SHIELD), Q10.2 (S)
unnamed: J1.A11 (SSRXP2), Q11.2 (S)
unnamed: J1.B2 (SSTXP2), Q14.2 (S)
unnamed: J1.B3 (SSTXN2), Q15.2 (S)
unnamed: J1.B4 (VBUS_B), J1.B9 (VBUS_B), Q16.2 (S), Q21.2 (S)
unnamed: J1.B5 (CC2), Q17.2 (S)
unnamed: J1.B6 (DP2), Q18.2 (S)
unnamed: J1.B7 (DN2), Q19.2 (S)
unnamed: J1.B8 (SBU2), Q20.2 (S)
unnamed: D2.A, R30.1
unnamed: J1.B10 (SSRXN1), Q22.2 (S)
unnamed: J1.B11 (SSRXP1), Q23.2 (S)
unnamed: D3.A, R31.1
unnamed: J1.S1 (SHELL_GND), J1.S2 (SHELL_GND), J1.S3 (SHELL_GND), J1.S4 (SHELL_GND), Q25.2 (S)
unnamed: D4.A, R32.1
unnamed: D5.A, R33.1
unnamed: D6.A, R34.1
unnamed: D7.A, R35.1
unnamed: D8.A, R36.1
unnamed: D9.A, R37.1
unnamed: D10.A, R38.1
unnamed: D11.A, R39.1
unnamed: D12.A, R40.1
unnamed: D13.A, R41.1
unnamed: D14.A, R42.1
unnamed: D15.A, R43.1
unnamed: D16.A, R44.1
unnamed: D17.A, R45.1
unnamed: D18.A, R46.1
unnamed: D19.A, R47.1
unnamed: D20.A, R48.1
unnamed: D21.A, R49.1
unnamed: D22.A, R50.1
unnamed: D23.A, R51.1
unnamed: D24.A, R52.1
unnamed: D25.A, R53.1
unnamed: J2.A1 (GND_A), J2.A12 (GND_A), R29.2, R40.2
unnamed: J2.A2 (SSTXP1), R30.2
unnamed: J2.A3 (SSTXN1), R31.2
unnamed: J2.A4 (VBUS_A), J2.A9 (VBUS_A), R32.2, R37.2
unnamed: J2.A5 (CC1), R33.2
unnamed: J2.A6 (DP1), R34.2
unnamed: J2.A7 (DN1), R35.2
unnamed: J2.A8 (SBU1), R36.2
unnamed: J2.A10 (SSRXN2), R38.2
unnamed: J2.A11 (SSRXP2), R39.2
unnamed: J2.B1 (GND_B), J2.B12 (GND_B), R41.2, R52.2
unnamed: J2.B2 (SSTXP2), R42.2
unnamed: J2.B3 (SSTXN2), R43.2
unnamed: J2.B4 (VBUS_B), J2.B9 (VBUS_B), R44.2, R49.2
unnamed: J2.B5 (CC2), R45.2
unnamed: J2.B6 (DP2), R46.2
unnamed: J2.B7 (DN2), R47.2
unnamed: J2.B8 (SBU2), R48.2
unnamed: J2.B10 (SSRXN1), R50.2
unnamed: J2.B11 (SSRXP1), R51.2
unnamed: J2.S1 (SHELL_GND), J2.S2 (SHELL_GND), J2.S3 (SHELL_GND), J2.S4 (SHELL_GND), R53.2

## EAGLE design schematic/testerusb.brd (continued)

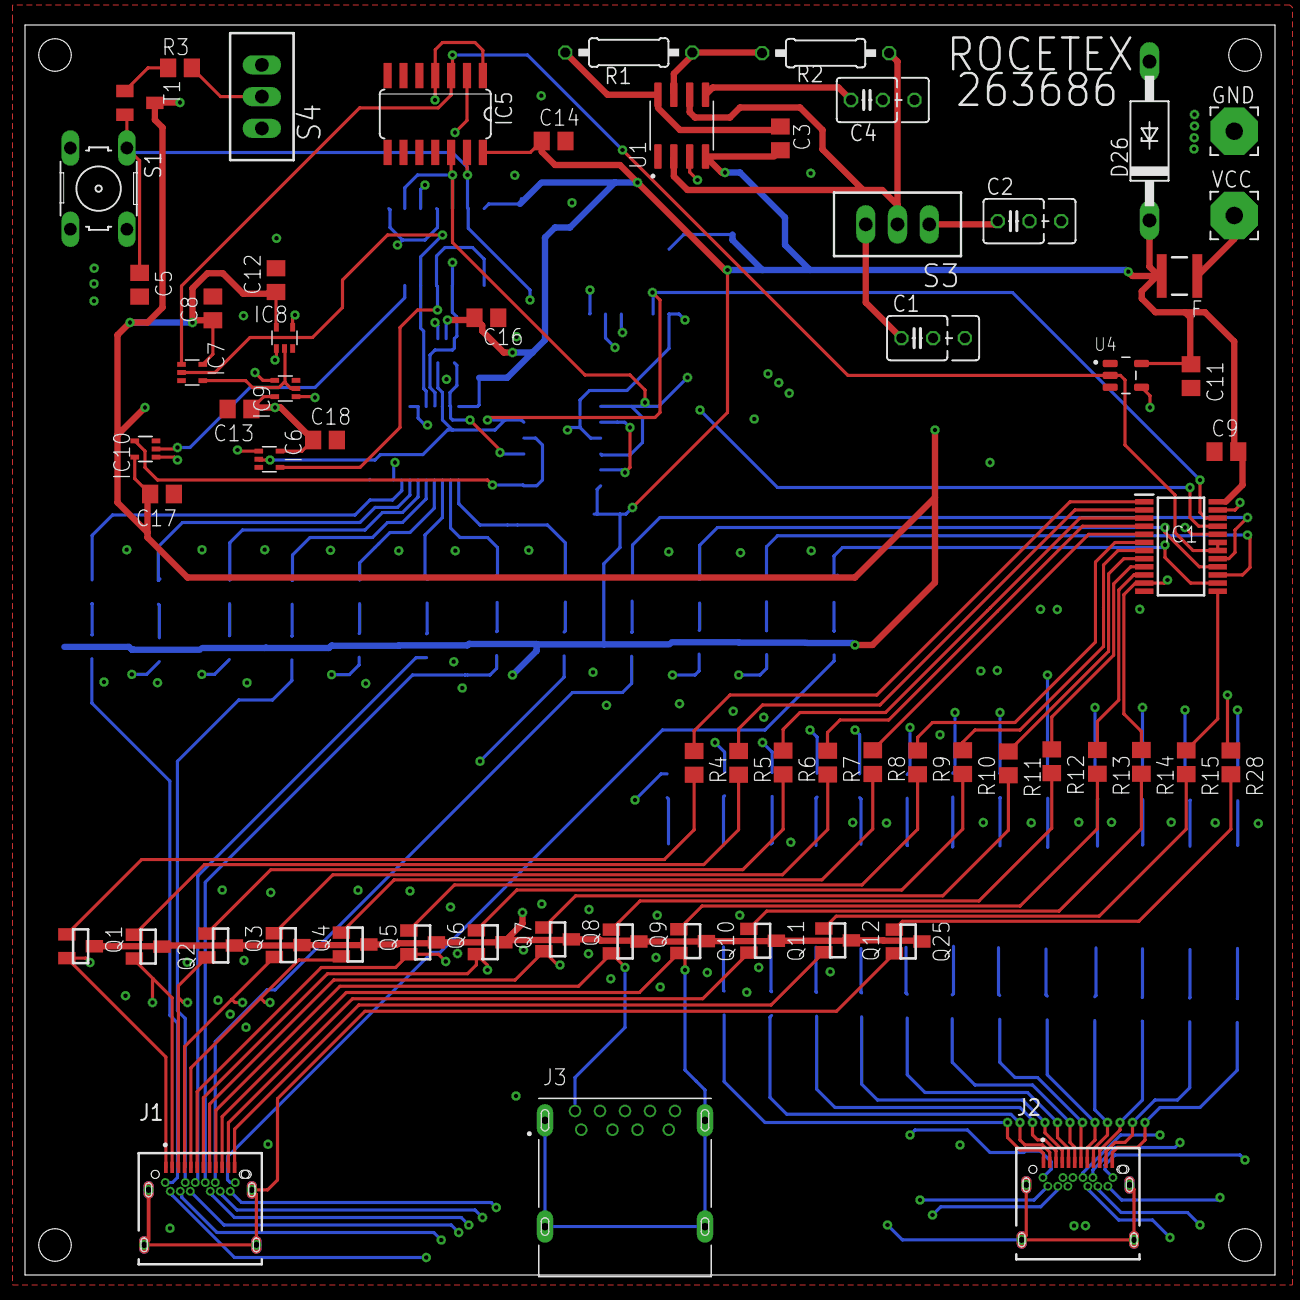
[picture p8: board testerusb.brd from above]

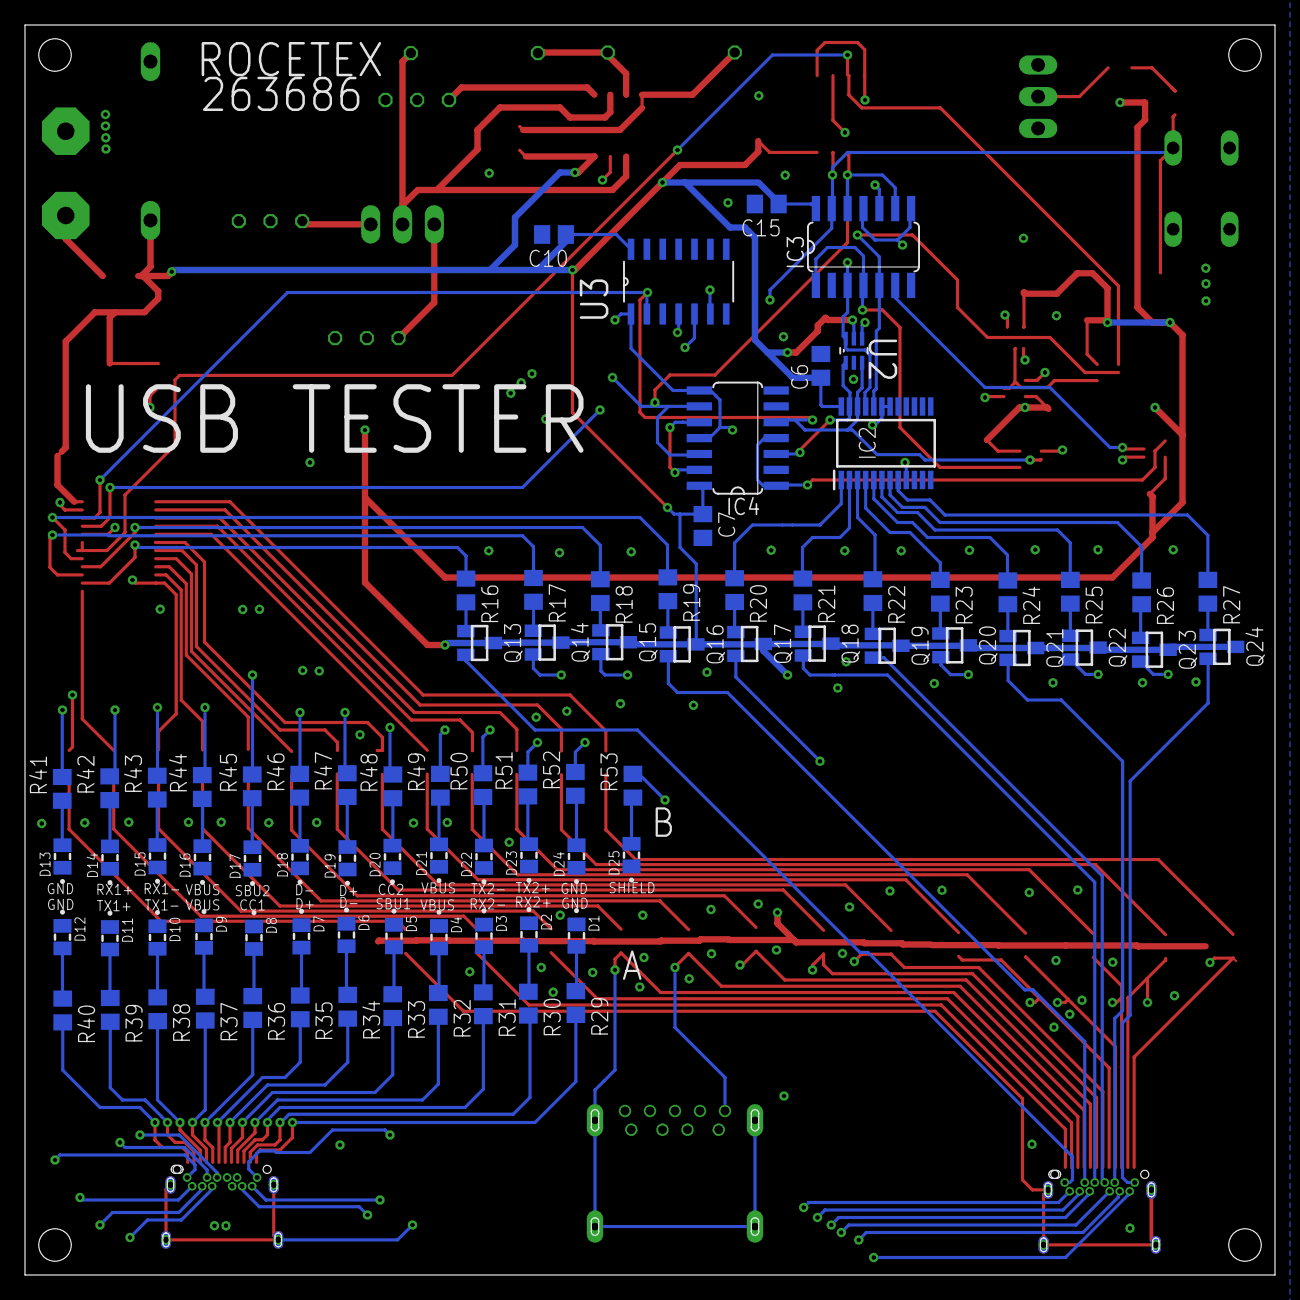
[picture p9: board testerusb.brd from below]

Board: 4 copper layers, 100.0 x 100.0 mm, 146 parts (83 on the bottom side), 145 nets.
